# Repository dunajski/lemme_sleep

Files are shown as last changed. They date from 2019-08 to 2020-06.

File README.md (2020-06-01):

# This repository was created to maintain work with projecting and building electronic device.

This simple device  should be able to do few simple tasks listed below:

* generate random numbers which is done with unstable LSB of ADC result :game_die:, 

* measure hold and release button time pressed by user :watch:,

* control vibrating motor with desired timer intervals,

* motor control on diffrent power sources with use of transistor and PWM, 

* smoothly working finite state machine with energy power saving state :battery:.

## Additional informations:

* in this project I used ATmega32 MCU,
* small (10 mm x 2 mm) vibrating motor.

### SUMMARY
* I won't continue develop on this repository.

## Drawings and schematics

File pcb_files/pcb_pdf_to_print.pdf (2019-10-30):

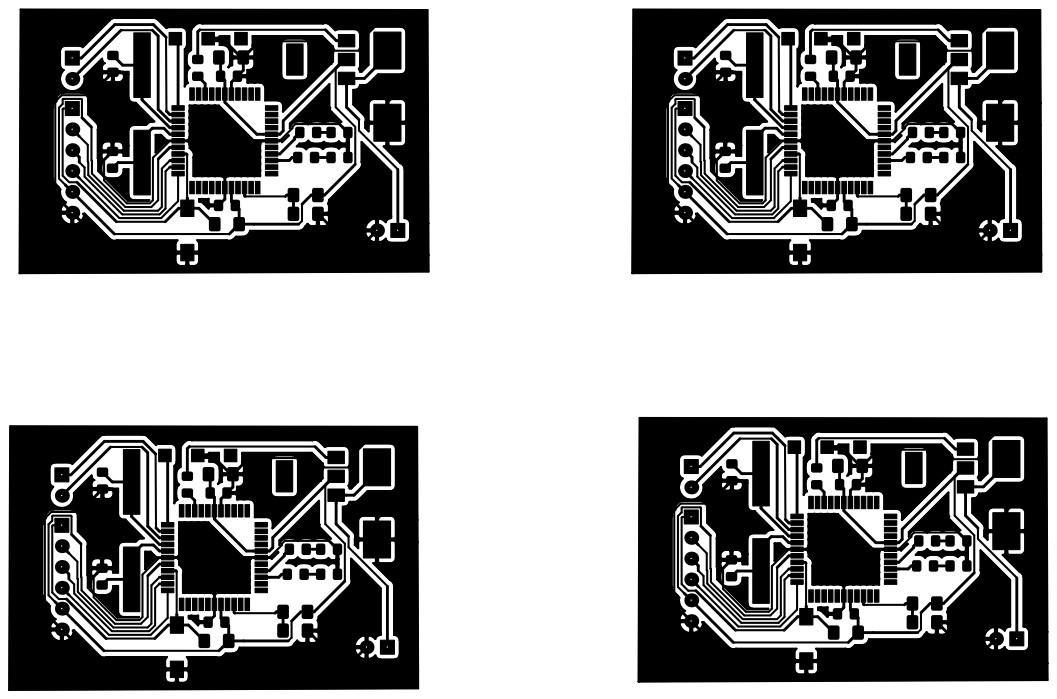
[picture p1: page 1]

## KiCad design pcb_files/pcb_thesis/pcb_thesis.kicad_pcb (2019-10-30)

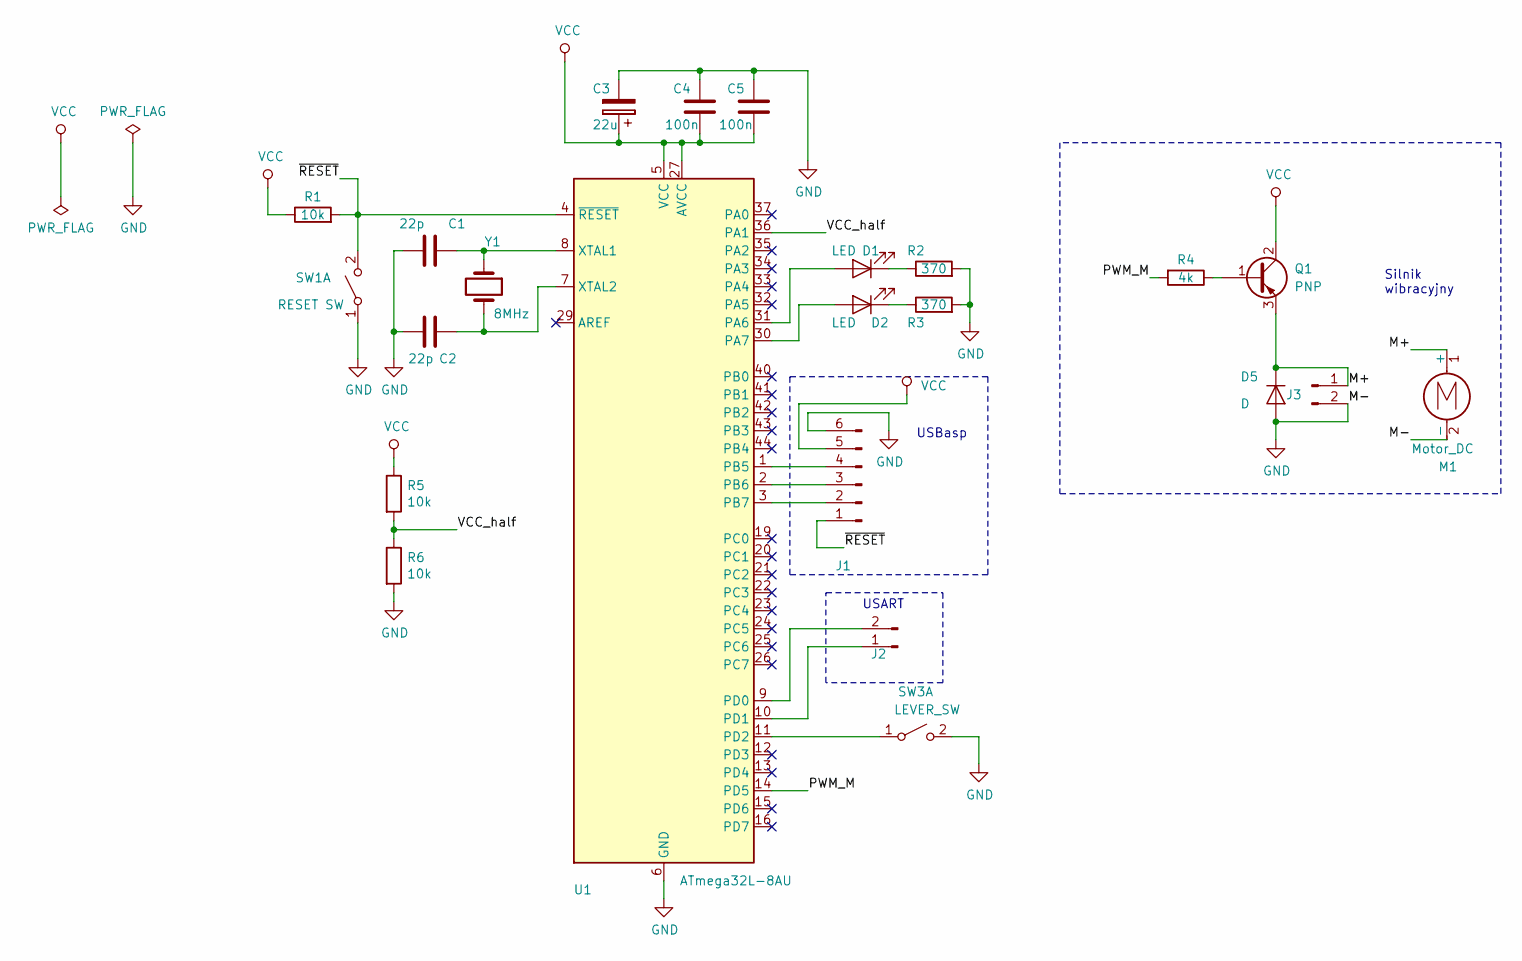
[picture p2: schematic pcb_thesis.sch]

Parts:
C1, C2: 22p; R_0805_2012Metric_Pad1.15x1.40mm_HandSolder
C3: 22u; R_1206_3216Metric_Pad1.42x1.75mm_HandSolder
C4, C5: 100n; R_0805_2012Metric_Pad1.15x1.40mm_HandSolder
D1, D2: LED; LED_0805_2012Metric_Pad1.15x1.40mm_HandSolder
D5: D; D_SMC_Handsoldering
J1: goldpin 1x6; PinHeader_1x06_P2.54mm_Horizontal
J2, J3: goldpin 1x2; PinHeader_1x02_P2.54mm_Horizontal
M1: Motor_DC
Q1: PNP; SOT-223
R1, R5, R6: 10k; R_1206_3216Metric_Pad1.42x1.75mm_HandSolder
R2, R3: 370; R_0805_2012Metric_Pad1.15x1.40mm_HandSolder
R4: 4k; R_0805_2012Metric_Pad1.15x1.40mm_HandSolder
SW1: RESET SW; SW_SPST_EVQPE1
SW3: LEVER_SW; MYSWITCHWITHLEWER
U1: ATmega32L-8AU; TQFP-44_10x10mm_P0.8mm
Y1: 8MHz; Crystal_SMD_HC49-SD_HandSoldering

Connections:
/PWM_M: R4.2, U1.14 (PD5)
/VCC_half: R5.2, R6.1, U1.36 (PA1)
/~RESET: J1.1, R1.2, SW1.2 (B), U1.4 (~RESET)
GND: C1.1, C2.1, C3.2, C4.1, C5.1, D5.2 (A), J1.6, J3.2, M1.2 (-), R2.2, R3.2, R6.2, SW1.1 (A), SW3.2 (B), U1.6 (GND), U1.18 (GND), U1.28 (GND), U1.39 (GND)
unnamed: C1.2, U1.8 (XTAL1), Y1.1
unnamed: C2.2, U1.7 (XTAL2), Y1.2
unnamed: D1.1 (K), R2.1
unnamed: D1.2 (A), U1.31 (PA6)
unnamed: D2.1 (K), R3.1
unnamed: D2.2 (A), U1.30 (PA7)
unnamed: D5.1 (K), J3.1, M1.1 (+), Q1.3 (E)
unnamed: J1.2, U1.3 (PB7)
unnamed: J1.3, U1.2 (PB6)
unnamed: J1.4, U1.1 (PB5)
unnamed: J2.1, U1.10 (PD1)
unnamed: J2.2, U1.9 (PD0)
unnamed: Q1.1 (B), R4.1
unnamed: SW3.1 (A), U1.11 (PD2)
VCC: C3.1, C4.2, C5.2, J1.5, Q1.2 (C), R1.1, R5.1, U1.5 (VCC), U1.17 (VCC), U1.27 (AVCC), U1.38 (VCC)

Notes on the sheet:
USART
Silnik wibracyjny
USBasp

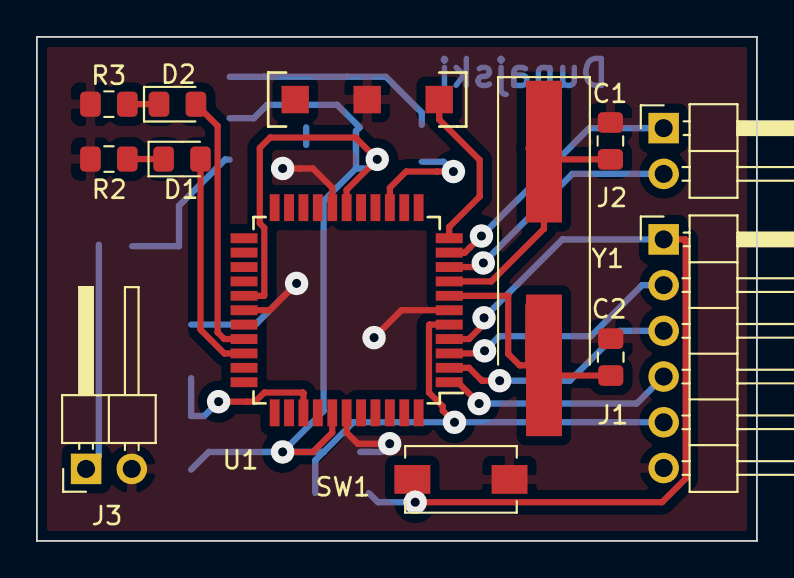
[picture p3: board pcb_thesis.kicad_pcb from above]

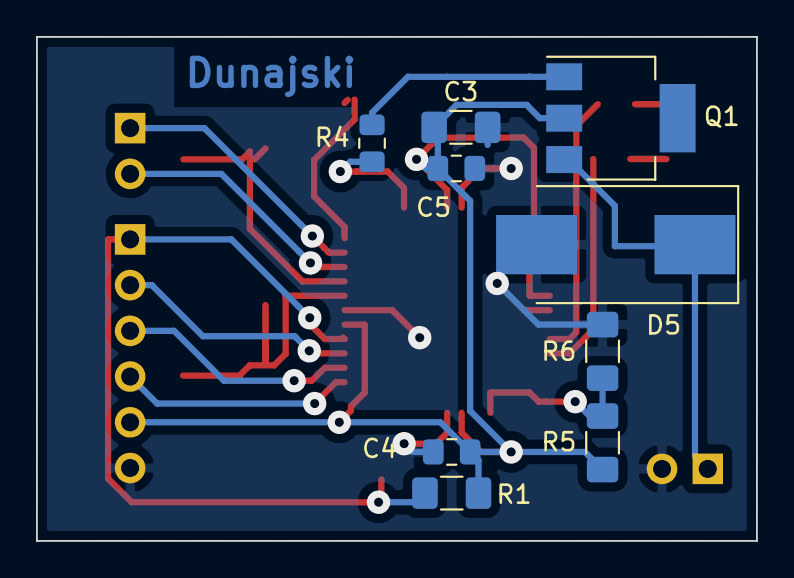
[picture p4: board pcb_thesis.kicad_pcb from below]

Board: 2 copper layers, 40.0 x 28.0 mm, 22 parts (9 on the bottom side), 19 nets.

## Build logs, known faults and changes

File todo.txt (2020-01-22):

Lista TODO:
Niestety jest critical w obsludze bramki tranzystora,
ze wzgledu na wyrzucenie sterowania napiecia zasilania,
na emiterze nalezy inaczej obsluzyc bramke.

Aby ograniczyc napiecie mozna "czesto" wlaczac i rozlaczac
tranzystora poprzez sterowanie bramka. Nalezy sprawdzic
predkosc zalaczania i rozlaczania tranzystora.

Wedlug noty katalogowej tranzystor ma czestotliwosc graniczna 115 MHz,
(niecale 9 ns :-D) a zakladam 10 ms (100 Hz) na sterowanie silnika.
Czyli najprosciej ujmujac jesli silnik ma byc zalaczony przez itnerwal
czasu X, ale napiecie na zaciskach przewyzsza maksymalne napiecie
dozwolone to napiecie powinno zostac wygenerowane w jak PWM.
To znaczy stan '1' i '0' na wejsciu bramki tranzystora
na tyle czesto na ile moze tranzystora i na tyle szybko by wplynelo to
na zachowanie silnika.

Przyklad jesli napiecie na emiterze rowne jest 5V, a dozwolone
maksymalne rowne jest 3,5V, a silnik ma byc uruchomiony przez X.
Z tego wychodzi, ze sumaryczny czas zalaczenia musi wynosi 0,7X.
To wszystko zadziala przy zalozeniu, ze mozna na tyle szybko
sterowac wyjsciem MCU oraz tranzystor jest w stanie sie przelaczyc.

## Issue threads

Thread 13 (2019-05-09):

zasilanie?

dunajski, 2019-05-09:
szukałem szukałem tego zasilania ale wychodzi na to, że najprościej bateria 9v i jakiś stabilizator napięcia czy tam stepdown.
Zapytać czy mogę taką..

dunajski, 2019-05-15:
Według założeń, można zrealizować wired urządzenie i ewentualnie opisać że jest taka możliwośc tyle że nie jest zaimplementowana. ATmega32L stestuj na 3V, masz step downa na dwóch bateriach (to na końcu).

Closed 2019-05-28.

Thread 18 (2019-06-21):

PWM/zasilanie/sterowanie silnika

dunajski, 2019-06-21:

dunajski, 2019-06-22:
Wybrano Timer1, Fast PWM.
Inverted mode toggle na wyjsciu MCU bo mam PNP.
Trzeba pomajstrowac z OCR1A zaleznie od zasilania :cat:

Closed 2019-09-26.

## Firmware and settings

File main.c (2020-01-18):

/*
 * main.c
 *      Author: Dunajski
 */
#define F_CPU 8000000

#include <stdio.h>
#include <avr/io.h>
#include <avr/interrupt.h>
#include <util/delay.h>

#include "communication.h"
#include "peripherals.h"
#include "random.h"
#include <util/delay.h>

int main(void)
{
  InitUsart();
  InitAdc();
  InitTimer0();
  InitTimer1();
  InitTimer2();
  InitIos();
  InitExternalInterupt1();
  sei();

  for (int i = 0; i < 5; i++)
  {
    STATE_LED_ON;
    MOTOR_ON;
    _delay_ms(5000);
    STATE_LED_OFF;
    MOTOR_OFF;
    _delay_ms(5000);
  }

  while (1)
  {
    // zaczynamy od pojscia spac i oczekujemy wybudzenia trzykrotnym nacisnieciem dzwigni
    if (device_state == ST_ENERGY_SAVING)
      GoToSleep();
  }

  return 0;
}

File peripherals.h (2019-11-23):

/*
 * peripherals.h
 *
 *  Created on: 17 sty 2019
 *      Author: Dunajski
 */

#ifndef PERIPHERALS_H_
#define PERIPHERALS_H_
#include "communication.h"
#include "random.h"
#include "types.h"

#define NUM_RND     13
#define MAX_NUM_ACTIONS  5

typedef struct PortABits
{
  volatile uchar adc_pin :1;    // PA 0 losowanie
  volatile uchar pwr_adc :1;    // PA 1 mierzenie napiecia zas
  volatile uchar :4;            // PA 2-5
  volatile uchar debug_led :1;  // PA 6
  volatile uchar state_led :1;  // PA 7
} TPortABits;

typedef struct PortDBits
{
  volatile uchar :2;            // PD 0-1
  volatile uchar action_lever:1;// PD 2
  volatile uchar :2;            // PD 3-4
  volatile uchar emiter :1;     // PD 5 (OCR1A)
  volatile uchar motor :1;      // PD 6
  volatile uchar :1;            // PD 7
} TPortDBits;

#define STATE_LED_VAL  ((TPortABits *)&PINA)->state_led
#define STATE_LED_DIR  ((TPortABits *)&DDRA)->state_led
#define STATE_LED_OUT ((TPortABits *)&PORTA)->state_led

#define DEBUG_LED_VAL  ((TPortABits *)&PINA)->debug_led
#define DEBUG_LED_DIR  ((TPortABits *)&DDRA)->debug_led
#define DEBUG_LED_OUT ((TPortABits *)&PORTA)->debug_led

#define ADC_PIN_VAL     ((TPortABits *)&PINA)->adc_pin
#define ADC_PIN_DIR     ((TPortABits *)&DDRA)->adc_pin
#define ADC_PIN_PULLUP ((TPortABits *)&PORTA)->adc_pin

#define PWR_ADC_VAL     ((TPortABits *)&PINA)->pwr_adc
#define PWR_ADC_DIR     ((TPortABits *)&DDRA)->pwr_adc
#define PWR_ADC_PULLUP ((TPortABits *)&PORTA)->pwr_adc

#define MOTOR_VAL  ((TPortDBits *)&PIND)->motor
#define MOTOR_DIR  ((TPortDBits *)&DDRD)->motor
#define MOTOR_OUT ((TPortDBits *)&PORTD)->motor

#define EMITER_VAL  ((TPortDBits *)&PIND)->emiter
#define EMITER_DIR  ((TPortDBits *)&DDRD)->emiter
#define EMITER_OUT ((TPortDBits *)&PORTD)->emiter

#define LEVER_VAL    ((TPortDBits *)&PIND)->action_lever
#define LEVER_DIR    ((TPortDBits *)&DDRD)->action_lever
#define LEVER_PULLUP ((TPortDBits *)&PORTD)->action_lever

#define DEBUG_LED_ON   (DEBUG_LED_OUT=1)
#define DEBUG_LED_OFF  (DEBUG_LED_OUT=0)
#define DEBUG_LED_TOGGLE  (DEBUG_LED_OUT=(!DEBUG_LED_OUT))

#define STATE_LED_ON   (STATE_LED_OUT=1)
#define STATE_LED_OFF  (STATE_LED_OUT=0)
#define STATE_LED_TOGGLE  (STATE_LED_OUT=(!STATE_LED_OUT))

#define MOTOR_ON   (MOTOR_OUT=0) // PNP bramka sterowana '0'
#define MOTOR_OFF  (MOTOR_OUT=1) // PNP bramka sterowana '0'

#define LEVER_PRESSED   (!LEVER_VAL)
#define LEVER_UNPRESSED (LEVER_VAL)

typedef struct
{
  uint16 hnr_time[MAX_NUM_ACTIONS];
  uint16 rnd_time[MAX_NUM_ACTIONS];
  uint16 extended_user_seq[MAX_NUM_ACTIONS];
  int16 diff_time[MAX_NUM_ACTIONS];
  uint32 whole_user_sequence;
  uint32 whole_random_sequence;
  uint32 whole_extended_user_seq;
  uint8 current_act;
} TLastSequence;

extern volatile TLastSequence Sequence;

typedef struct
{
  uint8 fails_in_row;
  uint8 num_actions;
  uint8 delay_between_sequences_s;
} TSequenceParameters;

extern volatile TSequenceParameters Seq_params;

/*
 *******************************************************************************
 * Funkcja do zmiany wartosci 16bitowej w bloku, uniemozliwiajacym nadpisanie
 * przez inne operacje. Do dzialania wymaga biblioteki util/atomic.h.
 * Operacja atomic wywolywana jest z przywroceniem stanu SREG (RestoreON).
 * [in] uint16 var_to_set - wskaznik na rejestr/zmienna do ustawienia
 * [in] uint16 value - wartosc do wpisania do rejestru/zmiennej
 *******************************************************************************
 */
void SetUint16_atomic(volatile uint16 * var_to_set, uint16 value);

/*
 *******************************************************************************
 * Inicjuje UART, 9600/8N1. Komunikacja na przerwaniach.
 *******************************************************************************
 */
void InitUsart(void);

/*
 *******************************************************************************
 * Inicjalizacja Timer0 do sterowania silnikiem (zalaczanie i rozlaczanie)
 * 10 ms CTC/presc. 1024.
 *******************************************************************************
 */
void InitTimer0(void);

/*
 *******************************************************************************
 * Inicjalizacja Timer1 do sterowania silnikiem (PWM, do sterowania zasilaniem
 * silnika, zaleznie od napiecia zasilania). Sterowanie wyjsciem OC1A (inverted
 * mode, bo uzywam PNP tranzystora do zalaczania silnika) Fast PWM/presc. 64.
 *******************************************************************************
 */
void InitTimer1(void);

/*
 *******************************************************************************
 * Inicjalizacja Timer2 do obslugi stanow oraz przycisku, 0,2 ms CTC/presc. 8.
 *******************************************************************************
 */
void InitTimer2(void);

/*
 *******************************************************************************
 * Inicjalizacja przetwornika do losowania zmiennych. ADC0, prescaler 64,
 * odniesienia na AVCC.
 *******************************************************************************
 */
void InitAdc(void);

/*
 *******************************************************************************
 * Inicjalizacja wejsc/wyjsc MCU. Tutaj ustawiam LEDy i stan poczatkowy appki.
 *******************************************************************************
 */
void InitIos(void);

/*
 *******************************************************************************
 * Przeprowadza procedure usypiania MCU, wylaczajac przerwania od wszystkich
 * peryferiow oprocz przerwania zewnetrznego. Nastepnie po przebudzeniu
 * przywraca wszystkie przerwania od peryferiow.
 *******************************************************************************
 */
void GoToSleep(void);

/*
 *******************************************************************************
 * Inicjalizacja External Interrupt 0 do wybudzania MCU. Stan niski na PD2.
 *******************************************************************************
 */
void InitExternalInterupt1(void);

/*
 *******************************************************************************
 *  Funkcja do wykonywania opoznienia miedzy kolejny stanami aplikacji.
 * [in] delay_s - ilosc sekund opoznienia miedzy kolejnymi stanami,
 * [in] next_state - stan (TDeviceStates) jaki ustawic po opoznieniu.
 *******************************************************************************
 */
void DelayandSetNextState(uint8 delay_s, uint8 next_state);

#endif /* PERIPHERALS_H_ */

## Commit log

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2019-01-21 added some pcb scheme files
    [pcb_thesis.kicad_pcb, pcb_thesis.sch]
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2019-04-07 powrot do kodu, problem z 0 0 0 0 ADC
    [main.c, peripherals.c, peripherals.h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]
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2019-04-15 dodano plik z probkami xls, sprawdzic czy dla wiekszej ilosci probek tez wychodzi taka nierownomiernosc
    [probki.xlsx]
2019-04-16 ~60k probek wylosowanych, ADC teraz uruchamiane poprzez key wartosci zapisywane sa do tablicy zakomentowano losowanie duzej ilosci probek, juz nie uzywane
    [probki.xlsx]
2019-04-18 obsluga klawisza w stanie interakcji wip
    dodano "substany" klawisza w trakcie interakcji, uin16_t powinien moc przechowac czas release i holda maks to az 26 sekund, nie przewiduje tak gluch probek nadawania stad jezeli ktos przekroczy ten s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
2019-04-18 update readme.md
    Added description about simple task that device should be able to do
2019-04-23 mierzenie interakcji wip
    proba zmierzenia czasu wcisniecia i odpuszczenia przycisku, na ten moment zbyt zakrecone ify sie wykladaja, ostatnie wcisniecie tj. 5te przerywa cala sekwencje. testy za pomoca debug led, czasy ISR s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
2019-04-24 added sending uint16 values via UART
    Dodano mozliwosc wysylania, przy uzyciu UART wartosci uint16 w celu zasymulowania sobie czasu wcisniecia i odpuszczenia przycisku. TODO: test measure hold and release
2019-05-01 added instruction and fixed pointer out of bound
    I added xmind map to show how state ST_INTERAKCJA works. I found out that I wasnt changing back position of pointer that I use so then after about 10 sequences program crashes.
    [peripherals.c, random.c]
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2019-05-07 Added posibility to Put Sint32 values to serial
    Those values are needed to send for future estimating actual activity of device user.
2019-05-08 device fsm improvemenet
    przygotwac FSM prawidlowe na razie zostaw ocene, ze zawsze zwraca ze uzytkownik :OK: powtorzyl sekwencje. funkcja do porownywarki. funkcja do poszerzenia ilosci czasu z wylosowanych wartosci.
2019-05-09 updated schematic files to be more actual
    [pcb_thesis.sch]
2019-05-15 updated pcb files
    divided schematic into parts and discarded option with source of energy but schematic is prepared for this feature
    [pcb_thesis.sch]
2019-05-15 description and small changes to schematic
    [pcb_thesis.sch]
2019-05-16 added some footprints and edgees for little chassis
    [pcb_thesis.kicad_pcb, pcb_thesis.sch]
2019-05-21 added few footprints and created two pcb boards WIP
    [pcb_thesis.sch, pcb_thesis_custom.kicad_pcb, probki.xlsx]
2019-05-23 pcb in progress
    [pcb_thesis.kicad_pcb, pcb_thesis.sch, pcb_thesis_custom.kicad_pcb]
2019-05-28 designing pcb WIP
    [black_box_pcb.kicad_pcb, pcb_thesis.kicad_pcb]
2019-05-30 przesunieto jedno zlacze blizej srodka plytki
    w rogach black boxa znajduja sie mocowanie dwoch czesci nie moga
    zachodzic na elementy bo nie ma tyle miejsca
    [pcb_thesis.kicad_pcb]
2019-06-21 W koncu dziala maszyna stanow urzadzenia
    Wciaz nie ma zaimplementowanej oceny interakcji, wiec po prostu pomija
    ten etap i przechodzi znow do uspienia ukladu. Po uspieniu nalezy
    trzykrotnie wcisnac przycisk aby wybudzic. Jesli w ciagu 10 sekund
    urzadzenie nie otrzyma 3 wcisniec ponownie przejdzie w stan oszczedzania
    energii. Brakuje PWMa do sterowania silnika zaleznie od zasilania i
    oceny. Nadaje sie do mastera.
2019-06-22 Dodanie inicjalizacji PWMa
    Timer0/2 zajete, do sterowania PWMa zastosuje Timer1, 16bitowy. Tryb
    Fast PWM, OC1A pin do sterowania silnikiem. Dodano obsluge atomic
    blokiem zapisu do zmiennej 16bitowej volatile (na potrzebe rejestru
    OCR1A).
2019-06-23 Added functionality to change ADC properties
    There is DC motor that need to be controlled with PWM because diffrent
    device's supply voltage. So to do that we need to switch between ADC
    configurations (one for drawing variables and second for measuring
    supply voltage). In datasheet manufacturer wrote that second adc
    conversion result after changing channel or ref voltage is viable. So
    second Conversion value is stored.
2019-06-24 Dodanie funkcji do obliczania i ustawiania OCR1A
    Funkcja na podstawie wyniku z ADC oblicza wartosc jaka musi przyjac PWM
    zeby silnik mial odpowiednie zasilanie. Zasilanie nie moze byc powyzej
    3,4v.
2019-06-30 Wprowadzenie sterowania napieciem zasilania
    Ze wzgledu na rozne napiecie zasilania e.g. 3v3,3v7,5v nalezy
    wprowadzic ograniczenie napiecia na zaciskach silnika. Stad sterowanie
    PWMem zaleznie od napiecia zasilania. Gdy napiecie jest ponizej
    granicznego (3v5) to takie samo napiecie jest na zaciskach silnika
    natomiast dla wyzszych napiec jest ograniczone. Testowane na LED.
2019-07-02 Wlaczenie oprocz LED silnika wibracyjnego
    Wczesniejsze proby byly bez silnika na ledzie, teraz jest silnik.
2019-08-11 synchro zrodel
    [pcb_thesis.kicad_pcb]
2019-08-21 gamma and beta and alfa factors
    [probki.xlsx]
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2019-10-16 Przygotowanie plikow do wytrawiania plytki
    [pcb_thesis.kicad_pcb, pcb_thesis.sch]
2019-10-30 Added all pcb files
    Mysle ze to wszystkie juz... i nie bedzie zmian.
    [pcb_thesis-B.Cu.gbr, pcb_thesis-B.Mask.gbr, pcb_thesis-B.SilkS.gbr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]
2019-12-14 Formatting pc this should be reverted
    [main.c]
2020-01-11 Poprawka w orientacji tranzystora
    Zamiana wyprowadzen tranzystora PNP na schemacie. Kardynalny blad z
    zamiana emitera z kolektorem. Uwaga, zmiana jest tylko na schemacie na
    plytce PCB pozostala stara wersja ze wzgledu na to ze plytka zostala
    juz wykonana. Rozwiazaniem tego problemu moze byc jakis trick z
    lutowaniem na plytce albo znalezie tranzystora z zamienonymi
    wyprowadzeniami.
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
